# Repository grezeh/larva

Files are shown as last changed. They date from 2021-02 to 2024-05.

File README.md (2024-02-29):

# larva
larva keyboard related sketches, materials, etc

# larva mk.2

larva

Mk.3 options:
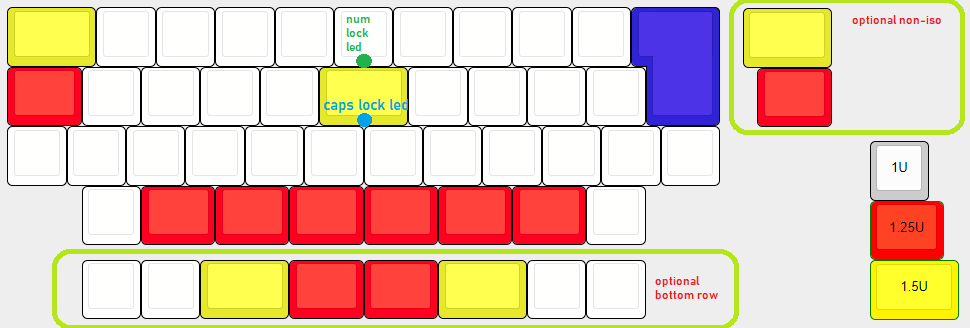
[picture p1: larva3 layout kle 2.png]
larva mk.3


 Larva keyboard is designed as part of a personal platform for research 
of combined, adaptable, extended latin+cyrillic keymap and layout with better ergonomics for day-to-day use.

 Keyboards, keymap, layouts are developed concurrently, work in symbiosis.
I name the whole research project "mnemoNИk|Kombine". 

 Larva PCB+custom plate fits in "daisy40% hhkb" keyboard case by Kprepublic.
Larva mk1 has 4 through-hole LED positions, no rgb, uses *AU mcu.

Mk2 has in addition 2 rgb smd LED slots for up-facing SK6812MINI-E LEDs 
and 2 pre-assembled mono-color smd LEDs as alternative to 2 lower through-hole LEDs(facedown, was an experimental feature)
and a few small QoL improvements. 

Mk2.1-light version cuts rgb and goes open-source. Pcbs routed by MarvFPV

Mk.3 pcb outline made smaller, to additionally fit "poseidon40" case by kprepublic. Added one more bottom row option and total-non-stab option (without iso enter). Modded by JLW, according to my specs (will see after the proto-run, how were the assumptions).

Current software-side implementation consists of QMK/vial +custom Windows keymap (needs updating).

Default keymap is basic latin+ numpad keycodes (looks chaotic, but gives more possibilities to reprogam); top-mid led is programmed as Num.Lock and it's engaged (put your novelties there and light them up; engaged numlock enables better bottom row options).

 For activating the bootloader: press the RST button on the back of the pcb.

 (The keyboard design line is constantly evolving, can differ in shapes and sizes, but all serve the same ultimate goal.
 Current line consists of: Larva mk1\mk2\mk2.1\mk3; Katerpillar; Katerpillar Infiltrator; Wodka; Wolof; Dragonfly; Butterfly; Mothra; Stargate; Galaga mk.1\mk.2\mk.3; Boardstroll)

* Keyboard Maintainer: [grezeh](https://github.com/grezeh)
* Hardware Supported: *Larva mk.2 pcb (atmega32u4)*
* Hardware Availability: *discord, occasionally, maybe*

QMK hex file compilation for this keyboard (after setting up your build environment,in QMK SYS for Qmk Toolbox):

    qmk compile -kb grezeh/larva/larva2 -km default (compiles locally, needs to go upstream at one point)

VIAL hex file compilation:
    
	qmk compile -kb grezeh/larva/larva2 -km vial (compiles locally. from vial git repo- not with recent changes; need to investigate, what new they implemented)

See the [build environment setup](https://docs.qmk.fm/#/getting_started_build_tools)
 and the [make instructions](https://docs.qmk.fm/#/getting_started_make_guide) for more information.
 Brand new to QMK? Start with our [Complete Newbs Guide](https://docs.qmk.fm/#/newbs).
 
 ps: lately vial have been giving errors, but locally still compiles fine. needs investigating
  (also, rgb is borked in current version- was experimental feature anyway, cut in version 2.1-light)
  
  oktoberfest'22- open sause the thing! 
  
  (now need to make "house in order", so noone brakes legs here. will upload simplified keymap later. Basically: need to upload qmk and vial files here, in addition to keymap)
  
  feedback on possible schematics flaws/improvements is appreciated

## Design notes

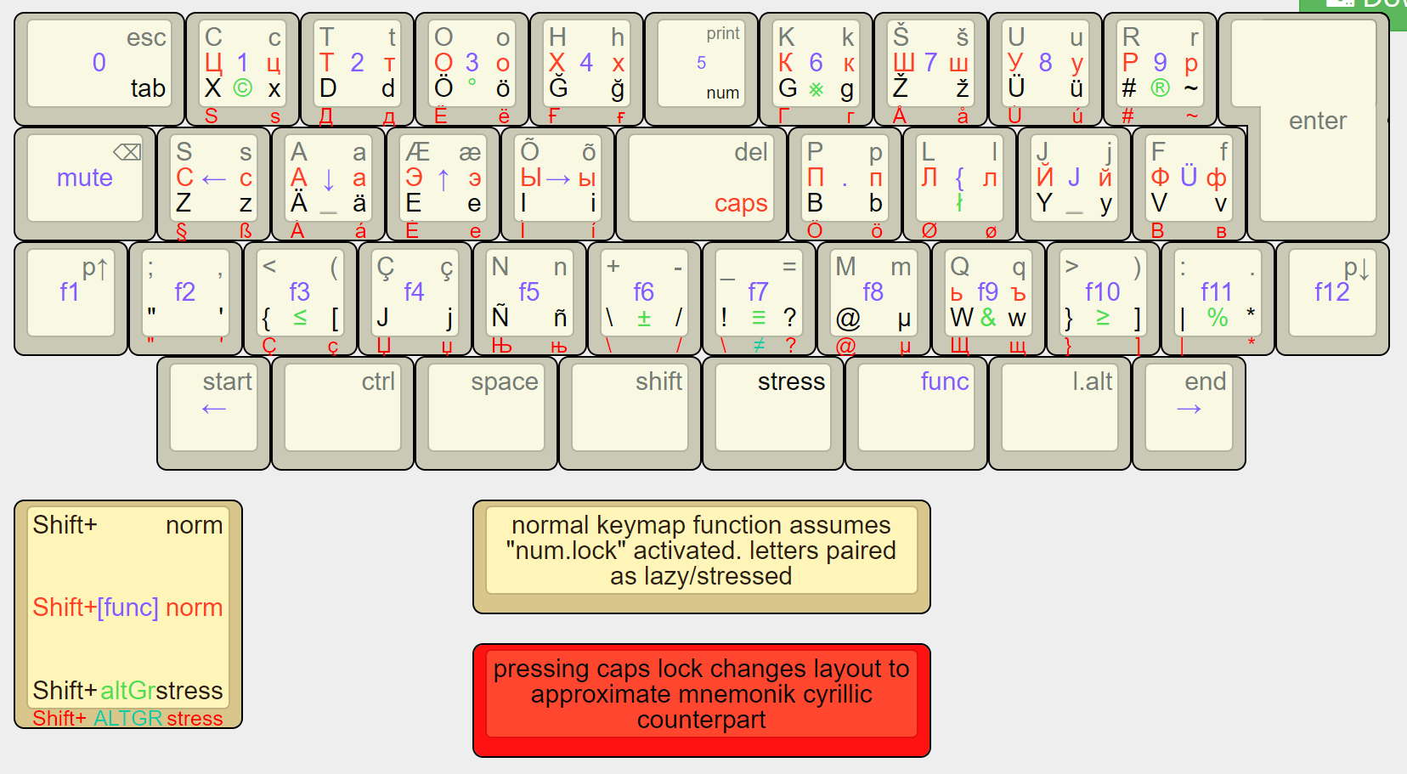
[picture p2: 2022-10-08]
mnæmoNИк (tяu xaos) keymap.png

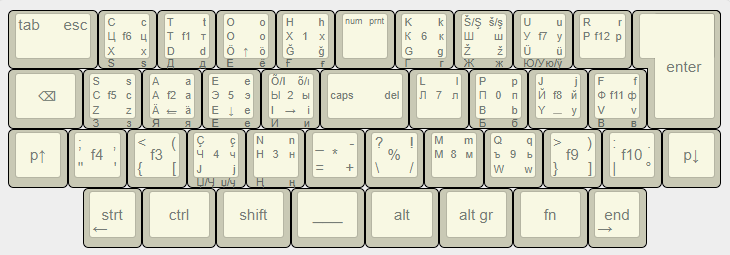
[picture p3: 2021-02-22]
mnemoNИk layout, initial adaptation for Larva.png

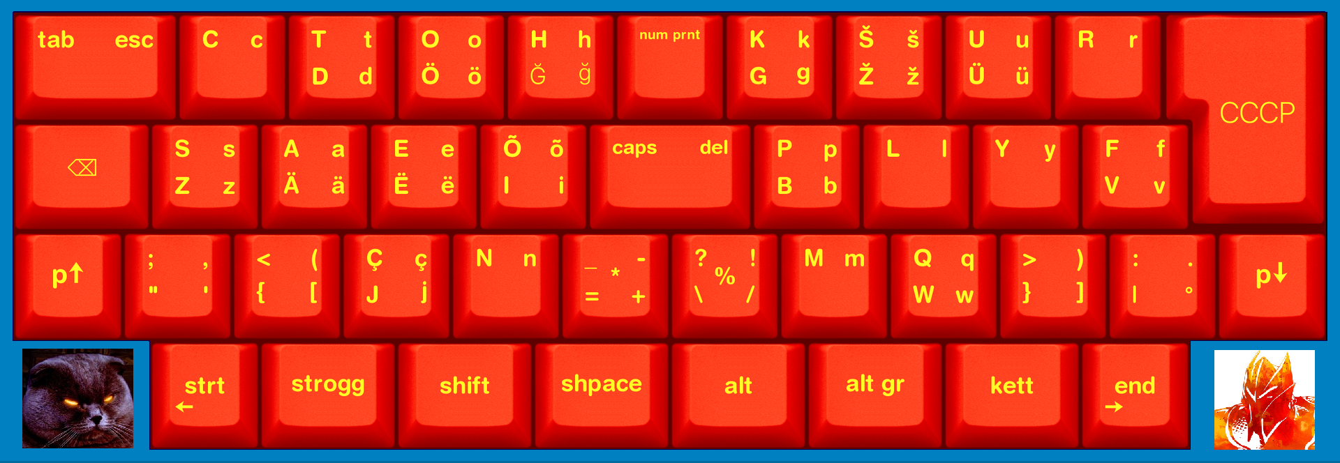
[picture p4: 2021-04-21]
ларва 2.png

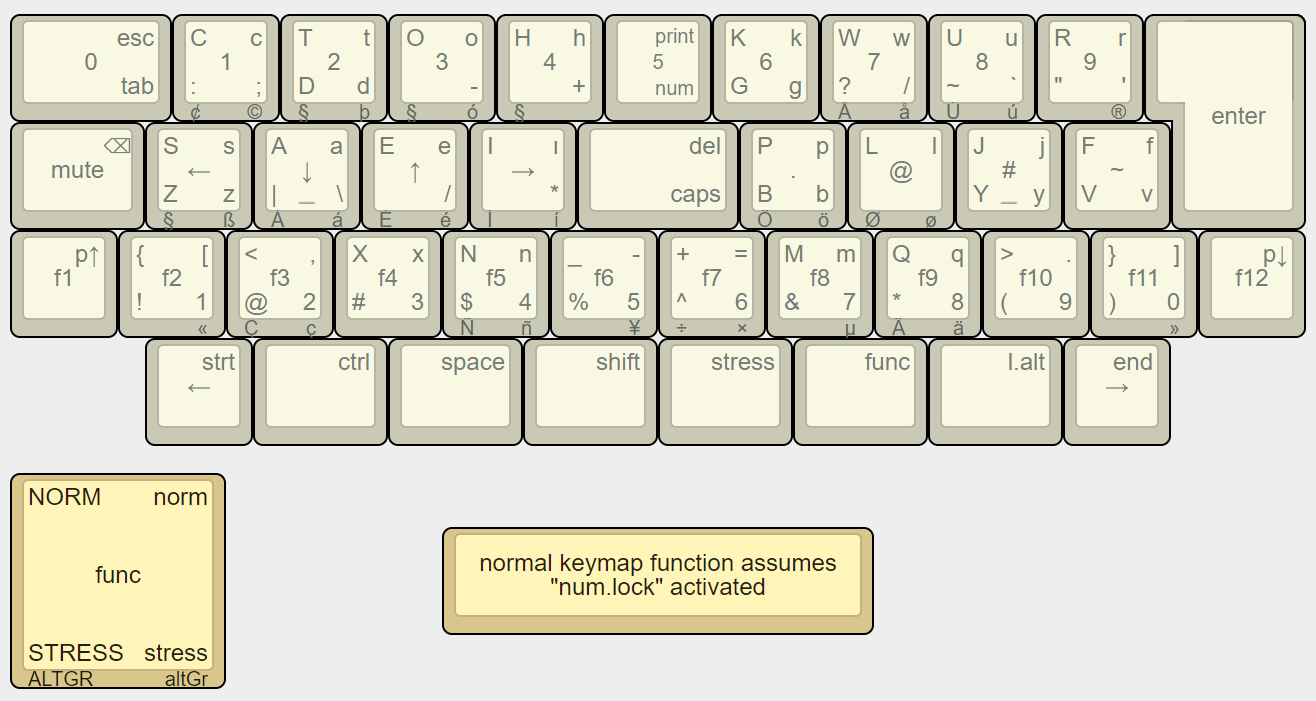
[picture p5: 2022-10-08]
simplified keymap.png

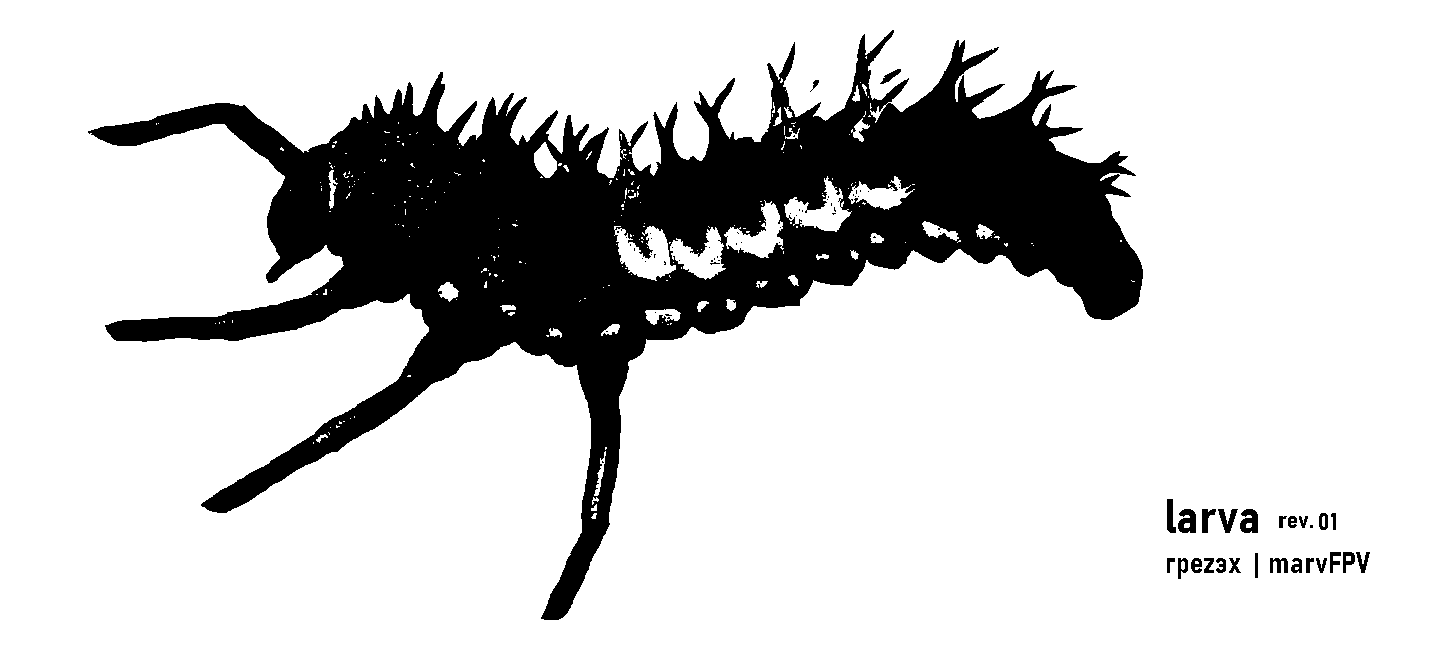
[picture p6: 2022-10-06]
Larva 2.1-light/larva_pcb_silkart.bmp

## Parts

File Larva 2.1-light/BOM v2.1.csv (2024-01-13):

Comment | Designator | Footprint | LCSC Part Number
680 | R9,R6,R8,R7 | R_0603_1608Metric | C23228
smd2 | D23 | LED_0603_1608Metric | C89811
smd1 | D18 | LED_0603_1608Metric | C375444
500mA | F1 | Fuse_1206_3216Metric | C69688
SK6812MINI | D25,D24 | SK6812MINI-E
Crystal_GND24_Small | Y1 | Crystal_SMD_3225-4Pin_3.2x2.5mm | C13738
22pF | C8,C7 | C_0603_1608Metric | C1653
ATmega32U4-AU | U1 | TQFP-44_10x10mm_P0.8mm | C44854
USB_C_Receptacle_USB2.0 | J2 | USB_C_Receptacle_HRO_TYPE-C-31-M-12 | C165948
USBLC6-2SC6 | U2 | SOT-23-6 | C7519
SW_Push | RST | SKQG-1155865 | C318884
10k | R11,R1 | R_0603_1608Metric | C25804
1M | R10 | R_0603_1608Metric | C269705
5.1k | R5,R4 | R_0603_1608Metric | C23186
22 | R3,R2 | R_0603_1608Metric | C23345
BAT54C | D22,D21,D20,D19,D17,D16,D15,D14,D13,D12,D11,D10,D9,D8,D7,D6,D5,D4,D3,D2,D1 | SOT-23 | C14308
1uF | C5 | C_0603_1608Metric | C15849
10uF | C4 | C_0603_1608Metric | C19702
0.1uF | C3,C2,C1,C10,C9,C6 | C_0603_1608Metric | C14663

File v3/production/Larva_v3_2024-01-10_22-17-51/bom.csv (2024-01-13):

Designator | Footprint | Quantity | Value | LCSC Part #
C1, C2, C3 | 603 | 3 | 0.1uF | C14663
C4 | 603 | 1 | 10uF | C19702
C5 | 603 | 1 | 1uF | C15849
C6 | 603 | 1 | 100nF
C7, C8 | 603 | 2 | 22pF | C1653
D1, D10, D11, D12, D13, D14, D15, D16, D17, D19, D2, D20, D21, D22, D3, D4, D5, D6, D7, D8, D9 | SOT-23 | 21 | BAT54C | C14308
D18 | 603 | 1 | smd1 | C375444
D23 | 603 | 1 | smd2 | C89811
D24 | 805 | 1 | LED | C434431
F1 | 1206 | 1 | 500mA | C69688
J1 | PinHeader_2x03_P2.54mm_Vertical | 1 | Conn_02x03_Odd_Even
J2 | USB_C_Receptacle_HRO_TYPE-C-31-M-12 | 1 | USB_C_Receptacle_USB2.0 | C165948
R1, R11 | 603 | 2 | 10k | C25804
R10 | 603 | 1 | 1M | C269705
R14 | 603 | 1 | 300 | C323659
R2, R3 | 603 | 2 | 22 | C23345
R4, R5 | 603 | 2 | 5.1k | C23186
R6, R7, R8, R9 | 603 | 4 | 680 | C23228
SW1 | SKQG-1155865 | 1 | SW_Push | C318884
U1 | QFN-44-1EP_7x7mm_P0.5mm_EP5.2x5.2mm | 1 | ATmega32U4-M
U2 | SOT-23-6 | 1 | USBLC6-2SC6 | C7519
Y1 | Crystal_SMD_3225-4Pin_3.2x2.5mm | 1 | Crystal_GND24_Small | C13738

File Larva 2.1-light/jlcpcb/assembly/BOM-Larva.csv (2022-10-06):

Comment | Designator | Footprint | LCSC
SW_Push | SW1 | SKQG-1155865 | C116647
Crystal_GND24_Small | Y1 | Crystal_SMD_3225-4Pin_3.2x2.5mm | C13738
0.1uF | C1,C2,C3,C6 | C_0603_1608Metric | C14663
1uF | C5 | C_0603_1608Metric | C15849
22pF | C7,C8 | C_0603_1608Metric | C1653
USB_C_Receptacle_USB2.0 | J2 | USB_C_Receptacle_HRO_TYPE-C-31-M-12 | C165948
10uF | C4 | C_0603_1608Metric | C19702
1M | R10 | R_0603_1608Metric | C22935
5.1k | R4,R5 | R_0603_1608Metric | C23186
680 | R6,R7,R8,R9 | R_0603_1608Metric | C23228
22 | R2,R3 | R_0603_1608Metric | C23345
10k | R1,R11 | R_0603_1608Metric | C25804
BAT54C | D1,D10,D11,D12,D13,D14,D15,D16,D17,D19,D2,D20,D21,D22,D3,D4,D5,D6,D7,D8,D9 | SOT-23 | C37704
ATmega32U4-M | U1 | QFN-44-1EP_7x7mm_P0.5mm_EP5.2x5.2mm | C45874
500mA | F1 | Fuse_1206_3216Metric | C69688
USBLC6-2SC6 | U2 | SOT-23-6 | C7519
MX-NoLED | MX1 | MXOnly-1.5U-NoLED
MX-NoLED | MX2 | MXOnly-1U-NoLED
MX-NoLED | MX3 | MXOnly-1U-NoLED
MX-NoLED | MX4 | MXOnly-1U-NoLED
MX-NoLED | MX5 | MXOnly-1U-NoLED
MX-NoLED | MX7 | MXOnly-1U-NoLED
MX-NoLED | MX8 | MXOnly-1U-NoLED
MX-NoLED | MX9 | MXOnly-1U-NoLED
MX-NoLED | MX10 | MXOnly-1U-NoLED
MX-NoLED | MX11 | MXOnly-1.25U-NoLED
MX-NoLED | MX12 | MXOnly-1U-NoLED
MX-NoLED | MX13 | MXOnly-1U-NoLED
MX-NoLED | MX14 | MXOnly-1U-NoLED
MX-NoLED | MX15 | MXOnly-1U-NoLED
MX-NoLED | MX17 | MXOnly-1U-NoLED
MX-NoLED | MX18 | MXOnly-1U-NoLED
MX-NoLED | MX19 | MXOnly-1U-NoLED
MX-NoLED | MX20 | MXOnly-1U-NoLED
MX-NoLED | MX21 | MXOnly-ISO-ROTATED-ReversedStabilizers-NoLED
MX-NoLED | MX22 | MXOnly-1U-NoLED
MX-NoLED | MX23 | MXOnly-1U-NoLED
MX-NoLED | MX24 | MXOnly-1U-NoLED
MX-NoLED | MX25 | MXOnly-1U-NoLED
MX-NoLED | MX26 | MXOnly-1U-NoLED
MX-NoLED | MX29 | MXOnly-1U-NoLED
MX-NoLED | MX30 | MXOnly-1U-NoLED
MX-NoLED | MX31 | MXOnly-1U-NoLED
MX-NoLED | MX32 | MXOnly-1U-NoLED
MX-NoLED | MX33 | MXOnly-1U-NoLED
MX-NoLED | MX34 | MXOnly-1U-NoLED
MX-NoLED | MX35 | MXOnly-1.25U-NoLED
MX-NoLED | MX36 | MXOnly-1.25U-NoLED
MX-NoLED | MX37 | MXOnly-1.25U-NoLED
MX-NoLED | MX38 | MXOnly-1.25U-NoLED
MX-NoLED | MX39 | MXOnly-1.25U-NoLED
MX-NoLED | MX40 | MXOnly-1.25U-NoLED
MX-NoLED | MX41 | MXOnly-1U-NoLED
MX-LED | MX6 | MXOnly-1U
MX-LED | MX16 | MXOnly-1.5U
MX-LED | MX27 | MXOnly-1U
MX-LED | MX28 | MXOnly-1U
Conn_02x03_Odd_Even | J1 | PinHeader_2x03_P2.54mm_Vertical
smd1 | D18 | LED_0603_1608Metric
smd2 | D23 | LED_0603_1608Metric
MountingHole | H1 | larvalogo3
MountingHole | H2 | larvasidelines

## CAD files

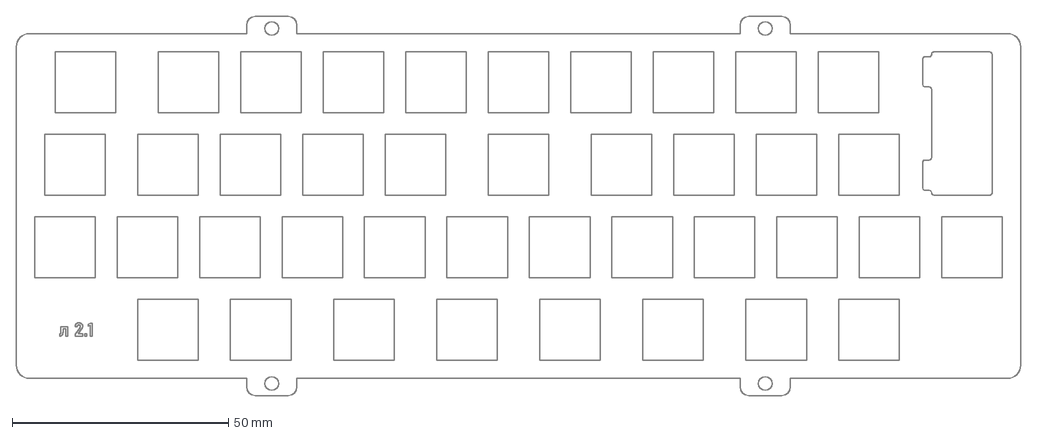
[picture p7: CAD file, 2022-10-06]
Larva 2.1-light/larva clean 2.1.dxf
232.0 x 87.6 mm

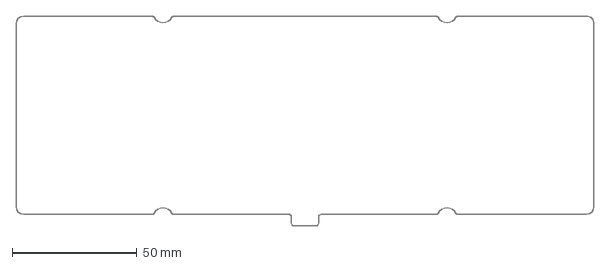
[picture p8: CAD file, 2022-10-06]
larva2 graphics/larva_pcb_outlineandpositions_withUSB v2 plus 1 mm.dxf
232.0 x 84.2 mm

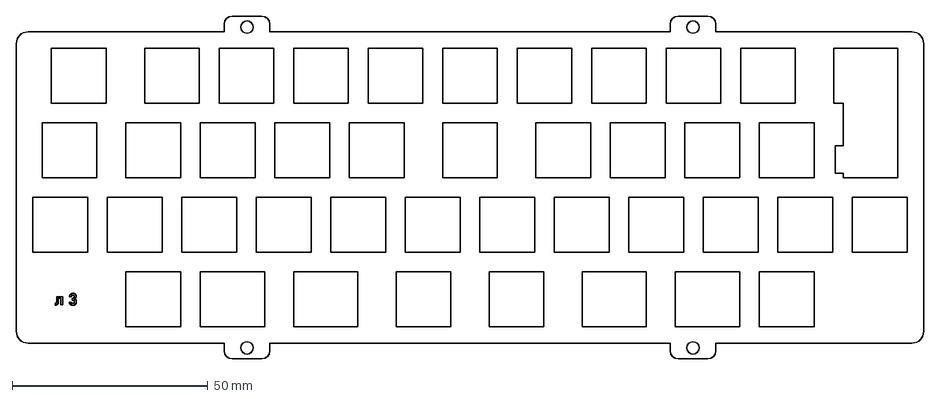
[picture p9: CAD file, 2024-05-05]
larva3 plate, top mount daisy.dxf
232.0 x 87.6 mm

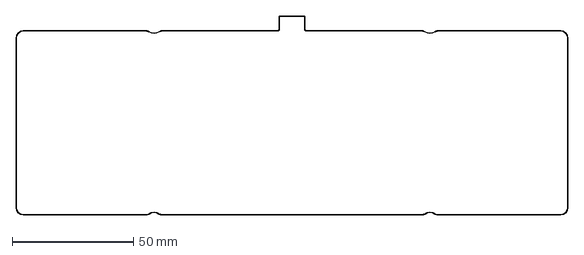
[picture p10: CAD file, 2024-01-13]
v3/larva_3_pcb_outline_10.7.dxf
228.0 x 82.1 mm

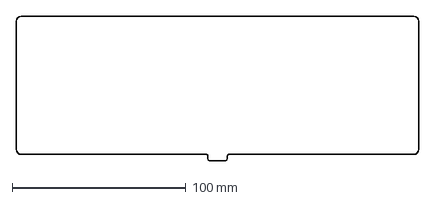
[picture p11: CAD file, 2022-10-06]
Larva 2.1-light/larva_pcb_outlineandpositions_withUSB.dxf
232.0 x 83.2 mm

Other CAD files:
Larva 2.1-light/larva_pcb_outlineandpositions.dxf

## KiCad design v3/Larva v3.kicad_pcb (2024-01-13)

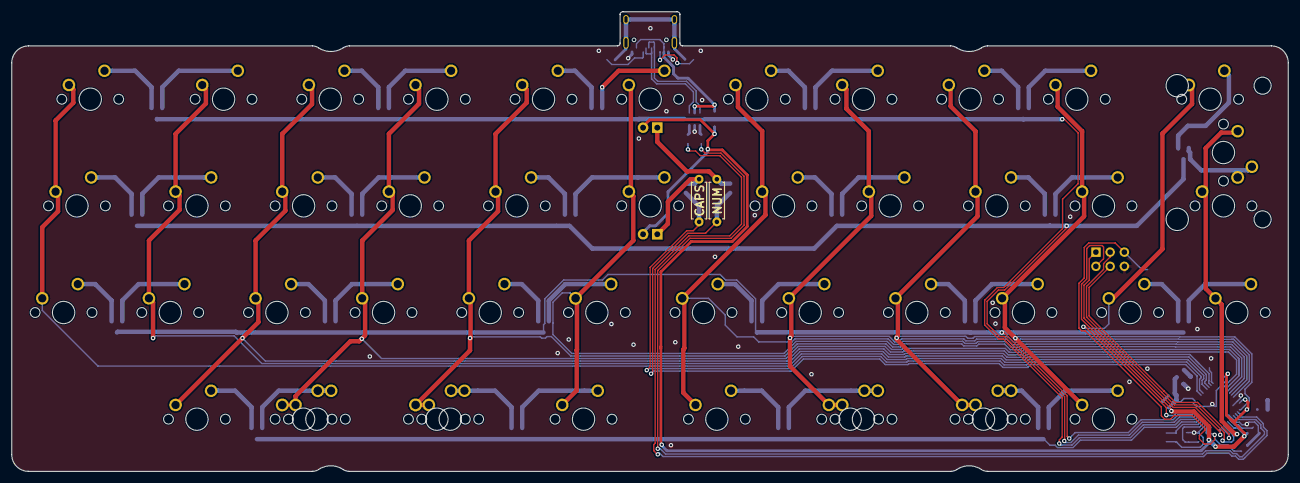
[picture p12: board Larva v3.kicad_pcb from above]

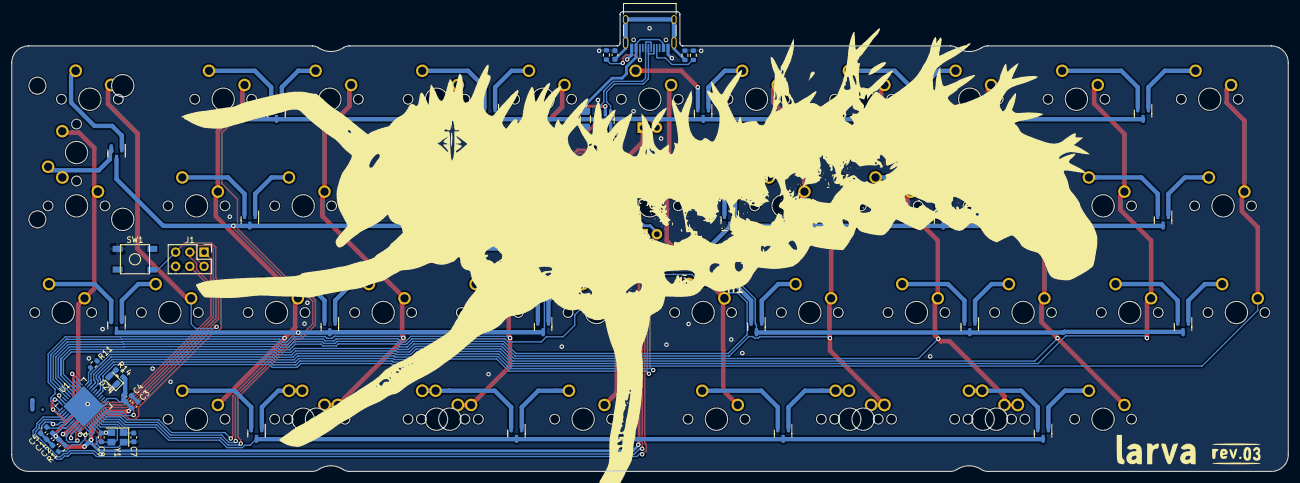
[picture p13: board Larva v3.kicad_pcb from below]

Board: 2 copper layers, 228.0 x 82.1 mm, 98 parts (49 on the bottom side), 83 nets.

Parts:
C1, C2, C3: 0.1uF; C_0603_1608Metric
C4: 10uF; C_0603_1608Metric
C5: 1uF; C_0603_1608Metric
C6: 100nF; C_0603_1608Metric
C7, C8: 22pF; C_0603_1608Metric
D1, D2, D3, D4, D5, D6, D7, D8, D9, D10, D11, D12, D13, D14, D15, D16, D17, D19, D20, D21, D22: BAT54C; SOT-23
D24: LED; LED_0805_2012Metric
F1: 500mA; Fuse_1206_3216Metric
H1: MountingHole; larvalogo3
H2: MountingHole; larvasidelines
J1: Conn_02x03_Odd_Even; PinHeader_2x03_P2.54mm_Vertical
J2: USB_C_Receptacle_USB2.0; USB_C_Receptacle_HRO_TYPE-C-31-M-12
MX1: MX-NoLED; MXOnly-1.5U-NoLED
MX2, MX3, MX4, MX5, MX7, MX8, MX9, MX10, MX12, MX13, MX14, MX15, MX17, MX18, MX19, MX20, MX22, MX23, MX24, MX25, MX26, MX29, MX30, MX31, MX32, MX33, MX34, MX41: MX-NoLED; MXOnly-1U-NoLED
MX6: MX-LED; MXOnly-1U
MX11, MX35, MX36, MX37, MX38, MX39, MX40: MX-NoLED; MXOnly-1.25U-NoLED
MX16: MX-LED; MXOnly-1.5U
MX21: MX-NoLED; MXOnly-ISO-ROTATED-ReversedStabilizers-NoLED
MX27, MX28: MX-LED; SW_MX_1u
MX42: MX-NoLED; SW_MX_1.25u
MX43, MX45, MX46: MX-NoLED; SW_MX_1.5u
MX44, MX47: MX-NoLED; SW_MX_1u
R1, R11: 10k; R_0603_1608Metric
R2, R3: 22; R_0603_1608Metric
R4, R5: 5.1k; R_0603_1608Metric
R7, R8: 680; R_0603_1608Metric
R10: 1M; R_0603_1608Metric
R12, R13: 680; R_Axial_DIN0207_L6.3mm_D2.5mm_P7.62mm_Horizontal
R14: 300; R_0603_1608Metric_Pad0.98x0.95mm_HandSolder
SW1: SW_Push; SKQG-1155865
U1: ATmega32U4-M; QFN-44-1EP_7x7mm_P0.5mm_EP5.2x5.2mm
U2: USBLC6-2SC6; SOT-23-6
Y1: Crystal_GND24_Small; Crystal_SMD_3225-4Pin_3.2x2.5mm

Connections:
+5V: C1.1, C2.1, C3.1, C4.1, F1.2, J1.2, MX6.3 (LED), MX16.3 (LED), R1.1, R14.1, U1.2 (UVCC), U1.7 (VBUS), U1.14 (VCC), U1.24 (AVCC), U1.34 (VCC), U1.44 (AVCC)
/Col0: MX1.1 (COL), MX11.1 (COL), MX22.1 (COL), U1.30 (PB6)
/Col1: MX2.1 (COL), MX12.1 (COL), MX23.1 (COL), U1.31 (PC6)
/Col2: MX3.1 (COL), MX13.1 (COL), MX24.1 (COL), MX34.1 (COL), U1.32 (PC7)
/Col3: MX4.1 (COL), MX14.1 (COL), MX25.1 (COL), MX35.1 (COL), MX44.1 (COL), U1.36 (PF7)
/Col4: MX5.1 (COL), MX15.1 (COL), MX26.1 (COL), MX36.1 (COL), MX45.1 (COL), U1.37 (PF6)
/Col5: MX6.1 (COL), MX16.1 (COL), MX27.1 (COL), MX37.1 (COL), U1.38 (PF5)
/Col6: MX7.1 (COL), MX17.1 (COL), MX28.1 (COL), MX38.1 (COL), U1.39 (PF4)
/Col7: MX8.1 (COL), MX18.1 (COL), MX29.1 (COL), MX39.1 (COL), MX46.1 (COL), U1.40 (PF1)
/Col8: MX9.1 (COL), MX19.1 (COL), MX30.1 (COL), MX40.1 (COL), MX47.1 (COL), U1.41 (PF0)
/Col9: MX10.1 (COL), MX20.1 (COL), MX31.1 (COL), MX41.1 (COL), U1.1 (PE6)
/Col10: MX32.1 (COL), MX43.1 (COL), U1.22 (PD5)
/Col11: MX21.1 (COL), MX33.1 (COL), MX42.1 (COL), U1.8 (PB0)
/D+: R2.2, U2.1 (I/O1)
/D-: R3.2, U2.3 (I/O2)
/LED0: MX6.4 (LEDGND), R8.1, R12.1
/LED1: MX16.4 (LEDGND), R7.1, R13.1
/LED_MID: R7.2, R13.2, U1.28 (PB4)
/LED_TOP: R8.2, R12.2, U1.27 (PD7)
/MISO: J1.1, U1.11 (PB3)
/MOSI: J1.4, U1.10 (PB2)
/RST: J1.5, R1.2, SW1.1, U1.13 (~RESET)
/Row0: D1.3, D2.3, D3.3, D4.3, D5.3, U1.19 (PD1)
/Row1: D6.3, D7.3, D8.3, D9.3, D10.3, D11.3, U1.20 (PD2)
/Row2: D12.3, D13.3, D14.3, D15.3, D16.3, D17.3, U1.21 (PD3)
/Row3: D19.3, D20.3, D21.3, D22.3, U1.18 (PD0)
/SCK: J1.3, U1.9 (PB1)
/USBD+: J2.A6 (D+), J2.B6 (D+), U2.6 (I/O1)
/USBD-: J2.A7 (D-), J2.B7 (D-), U2.4 (I/O2)
GND: C1.2, C2.2, C3.2, C4.2, C5.2, C6.2, C7.2, C8.1, D24.1 (K), J1.6, J2.A1 (GND), J2.A12 (GND), J2.B1 (GND), J2.B12 (GND), R4.1, R5.2, R10.1, R11.2, SW1.2, U1.5 (UGND), U1.15 (GND), U1.23 (GND), U1.35 (GND), U1.43 (GND), U1.45 (GND), U2.2 (GND), Y1.2, Y1.4
unnamed: D24.2 (A), R14.2
unnamed: J2.A5 (CC1), R4.2
unnamed: J2.B5 (CC2), R5.1
unnamed: C6.1, J2.S1 (SHIELD), R10.2
unnamed: D1.1, MX1.2 (ROW)
unnamed: D1.2, MX2.2 (ROW)
unnamed: D2.1, MX3.2 (ROW)
unnamed: D2.2, MX4.2 (ROW)
unnamed: D3.1, MX5.2 (ROW)
unnamed: D3.2, MX6.2 (ROW)
unnamed: D4.1, MX7.2 (ROW)
unnamed: D4.2, MX8.2 (ROW)
unnamed: D5.1, MX9.2 (ROW)
unnamed: D5.2, MX10.2 (ROW)
unnamed: D6.1, MX11.2 (ROW)
unnamed: D6.2, MX12.2 (ROW)
unnamed: D7.1, MX13.2 (ROW)
unnamed: D7.2, MX14.2 (ROW)
unnamed: D8.1, MX15.2 (ROW)
unnamed: D8.2, MX16.2 (ROW)
unnamed: D9.1, MX17.2 (ROW)
unnamed: D9.2, MX18.2 (ROW)
unnamed: D10.1, MX19.2 (ROW)
unnamed: D10.2, MX20.2 (ROW)
unnamed: D11.2, MX21.2 (ROW), MX42.2 (ROW)
unnamed: D12.1, MX22.2 (ROW)
unnamed: D12.2, MX23.2 (ROW)
unnamed: D13.1, MX24.2 (ROW)
unnamed: D13.2, MX25.2 (ROW)
unnamed: D14.1, MX26.2 (ROW)
unnamed: D14.2, MX27.2 (ROW)
unnamed: D15.1, MX28.2 (ROW)
unnamed: D15.2, MX29.2 (ROW)
unnamed: D16.1, MX30.2 (ROW)
unnamed: D16.2, MX31.2 (ROW)
unnamed: D17.1, MX32.2 (ROW)
unnamed: D17.2, MX33.2 (ROW)
unnamed: D19.1, MX34.2 (ROW)
unnamed: D19.2, MX35.2 (ROW), MX44.2 (ROW)
unnamed: D20.1, MX36.2 (ROW), MX45.2 (ROW)
unnamed: D20.2, MX37.2 (ROW)
unnamed: D21.1, MX38.2 (ROW)
unnamed: D21.2, MX39.2 (ROW), MX46.2 (ROW)
unnamed: D22.1, MX40.2 (ROW), MX47.2 (ROW)
unnamed: D22.2, MX41.2 (ROW)
unnamed: D11.1, MX43.2 (ROW)
unnamed: R2.1, U1.4 (D+)
unnamed: R3.1, U1.3 (D-)
unnamed: C5.1, U1.6 (UCAP)
unnamed: C7.1, U1.17 (XTAL1), Y1.1
unnamed: C8.2, U1.16 (XTAL2), Y1.3
unnamed: R11.1, U1.33 (~HWB/PE2)
VCC: F1.1, J2.A4 (VBUS), J2.A9 (VBUS), J2.B4 (VBUS), J2.B9 (VBUS), U2.5 (VBUS)

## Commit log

2021-02-22 Add files via upload
    mnemoNИk on Larva, initial. (working on it still)
2021-02-22 Add files via upload
    mnemoNИк layout on Larva, wip (KLE)
2021-02-22 Add files via upload
    mnemoNИk layout on Larva. wip (KLE)
2021-02-22 Add files via upload
    mnemoNИk layout, adapted for Larva. ver 02
2021-02-22 Add files via upload
    mnemoNИk layout on Larva. (wip KLE)
2022-10-06 Add files via upload
    open sause
    [BOM-Larva.csv, BOM.csv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]
2022-10-06 simplified plate, no kerf [fur laserboost]
    [larva clean 2.1.dxf]
2022-10-08 mnæmoNИк хаоѕ layout
2022-10-08 mnæmoNИк хаоѕ layout KLE raw
2022-10-08 Update mnæmoNИк (tяu xaos) keymap.txt
2022-10-08 mnæmoNИк (tяu xaos) layout update
2023-12-20 started v3 work
    [BOM-Larva.csv, BOM.csv, larva clean 2.1.dxf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]
2024-01-11 update LEDs
    [Larva v3.kicad_pcb, positions (1).csv, positions.csv]
2024-05-05 larva3 plate, universal, top-mount for Daisy
    larva3 plate, top-mount for Daisy. (not yet tested)
    [larva3 plate, top mount daisy.dxf]
